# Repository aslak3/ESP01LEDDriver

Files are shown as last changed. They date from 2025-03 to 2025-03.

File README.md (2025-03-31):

# ESP01LEDDriver: a board for attaching an ESP01 to an addressable LED strip

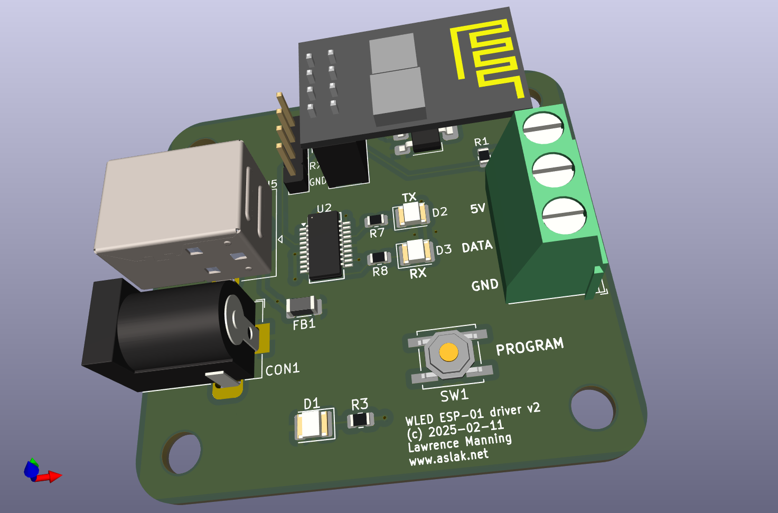
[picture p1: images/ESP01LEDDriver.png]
ESP01LEDDriver PCB


A [schematic](ESP01LEDDriver.pdf) is included here, along with the
[KiCAD](https://www.kicad.org) data files, whcih are in KiCAD 6 format.

## PCB design

The PCB is a trivial 2 layer board.

## Using

After coming across the
[ESP01](https://www.instructables.com/Getting-Started-With-the-ESP8266-ESP-01/)
I was very impressed. It seemed like an excellent solution to problems where a
very small controller board was needed, such as running
[WLED](https://kno.wled.ge) to control addressable LED strips. However the LED
strip attachment board I could find used an odd arrangement of receiving power
by attaching a USB-A plug directly to the board. I wanted to use a power lead of
some description, going to the controller board which then had the LED strip
screwed into it on terminals. As I was ordering some other boards, I thought I
would knock up this board and order it at the same time.

Power can be supplied via 5V on the barell plug, or 5V via a USB-B connector.
The [FTDI
FT231XS](https://ftdichip.com/wp-content/uploads/2021/10/DS_FT231X.pdf) is
optional: if included on the board then it is possible to program the ESP01
in-place via the USB connection. Otherwise it must either be programmed using a
dedicated board, or programmed when attached to this board but via a USB TTL (in
3.3V mode!) UART attached to the four header pins.

In either case, the PROGRAM button can be used to bring up the ESP01 in
programming mode.

## TODO

When time allows I will CAD-up a small printable case for enclosing this board.

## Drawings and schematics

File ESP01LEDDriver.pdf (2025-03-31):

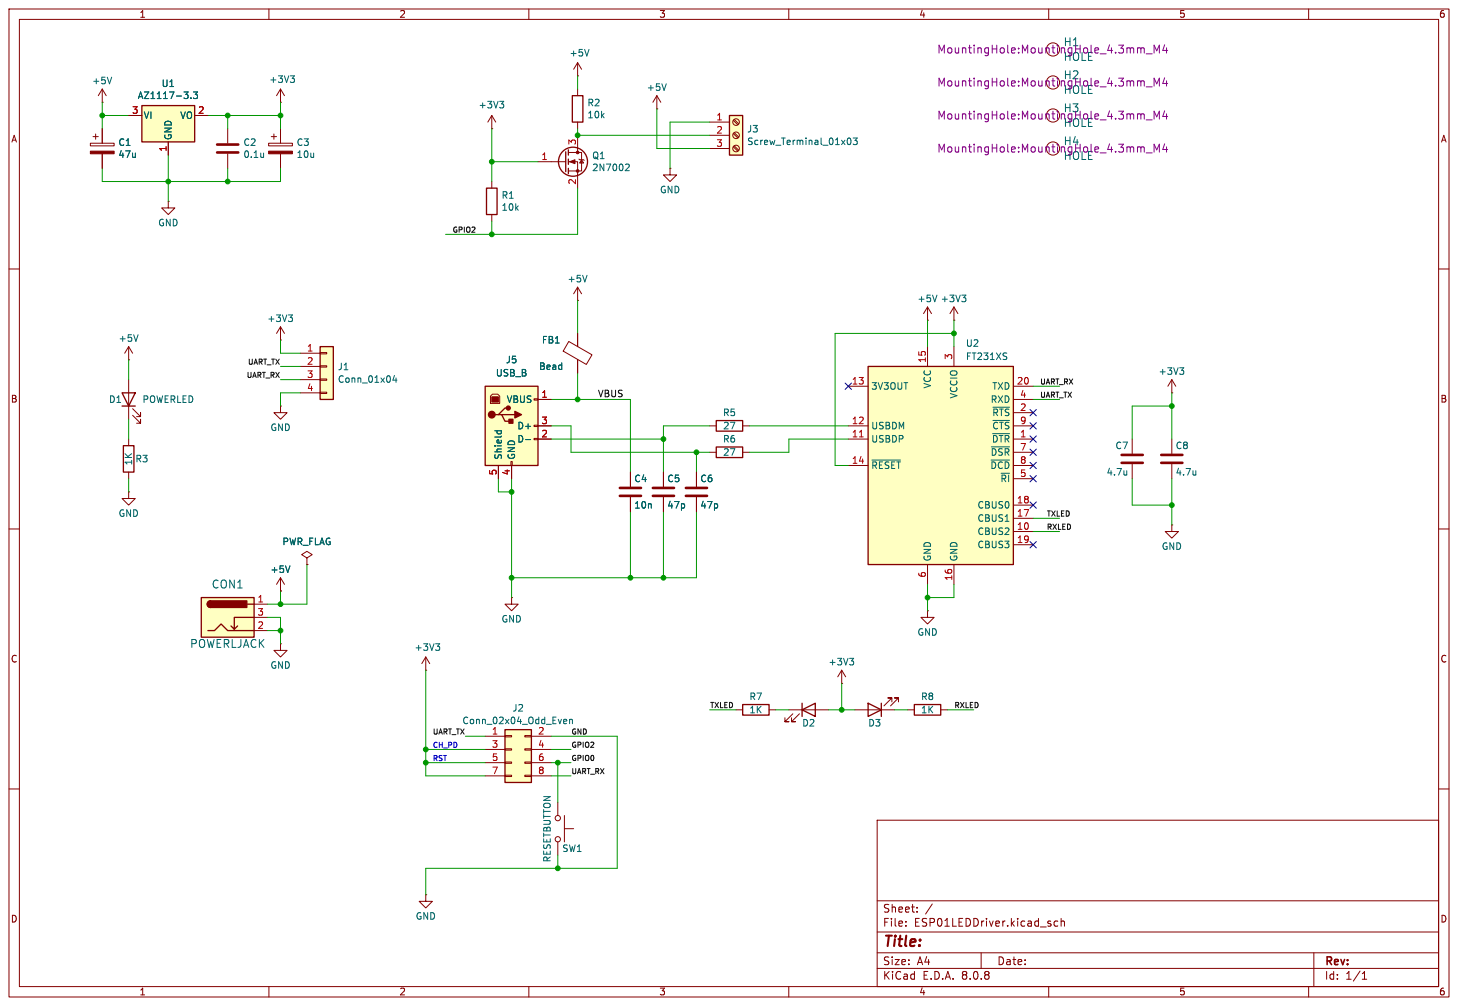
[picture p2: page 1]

Id: 1/1 Title: File: ESP01LEDDriver.kicad_sch Sheet: /

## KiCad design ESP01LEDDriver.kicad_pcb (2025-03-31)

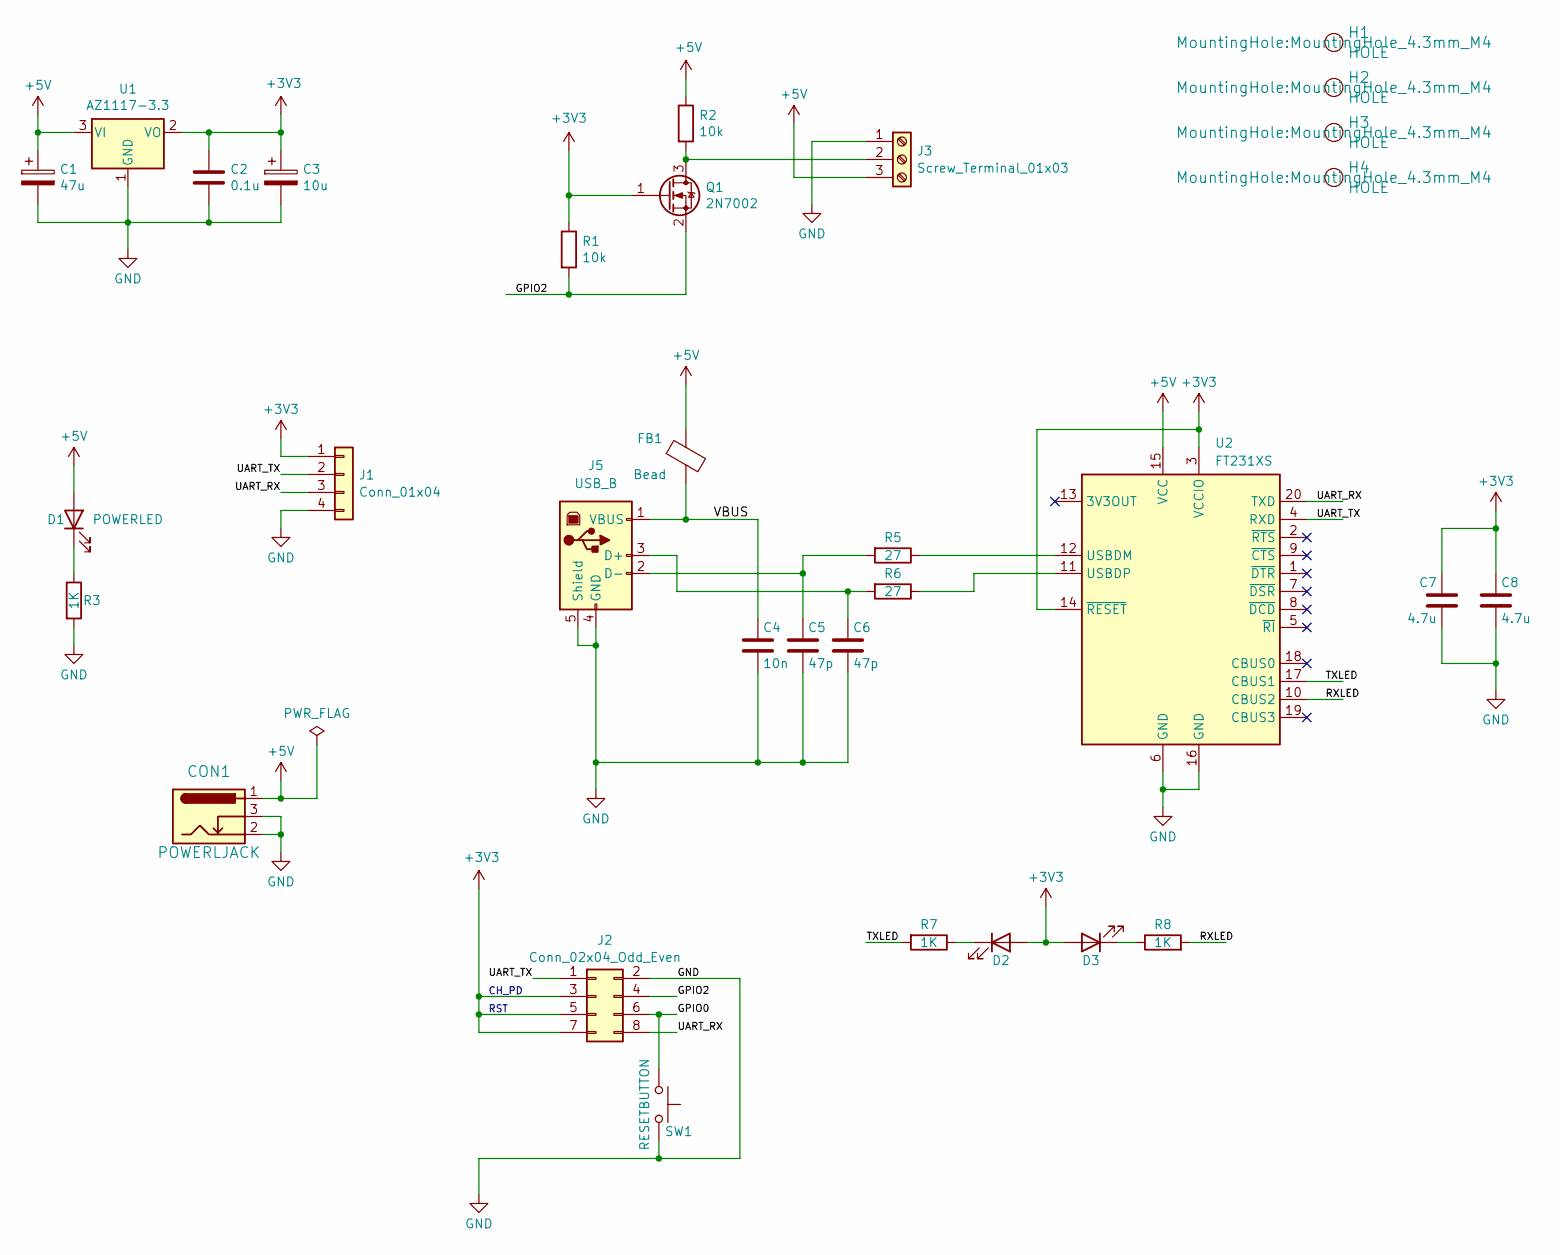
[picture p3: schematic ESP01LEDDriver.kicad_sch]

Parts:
C1: 47u; CP_EIA-7343-15_Kemet-W
C2: 0.1u; C_0805_2012Metric
C3: 10u; CP_EIA-3216-10_Kemet-I
C4: 10n; C_0805_2012Metric
C5, C6: 47p; C_0805_2012Metric
C7, C8: 4.7u; C_0805_2012Metric
CON1: POWERLJACK; BarrelJack_Horizontal
D1: POWERLED; LED_1210_3225Metric
D2, D3: UART_LED; LED_1210_3225Metric
FB1: Bead; L_1206_3216Metric
H1, H2, H3, H4: HOLE; MountingHole_4.3mm_M4
J1: Conn_01x04; PinHeader_1x04_P2.54mm_Vertical
J2: Conn_02x04_Odd_Even; PinHeader_2x04_P2.54mm_Vertical
J3: Screw_Terminal_01x03; TerminalBlock_Philmore_TB133_1x03_P5.00mm_Horizontal
J5: USB_B; USB_B_OST_USB-B1HSxx_Horizontal
Q1: 2N7002; SOT-23; LCSC C8545
R1, R2: 10k; R_0805_2012Metric; LCSC C17414
R3, R7, R8: 1K; R_0805_2012Metric
R5, R6: 27; R_0805_2012Metric
SW1: RESETBUTTON; SW_Push_1P1T_NO_CK_KSC6xxJ
U1: AZ1117-3.3; SOT-223-3_TabPin2
U2: FT231XS; SSOP-20_3.9x8.7mm_P0.635mm

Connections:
+3V3: C2.1, C3.1, C7.1, C8.1, D2.2 (A), D3.2 (A), J1.1, J2.3, J2.5, J2.7, Q1.1 (G), R1.1, U1.2 (VO), U2.3 (VCCIO), U2.14 (~RESET)
+5V: C1.1, CON1.1, D1.2 (A), FB1.1, J3.3, R2.1, U1.3 (VI), U2.15 (VCC)
/GPIO0: J2.6, SW1.1
/GPIO2: J2.4, Q1.2 (S), R1.2
/RXLED: R8.2, U2.10 (CBUS2)
/TXLED: R7.2, U2.17 (CBUS1)
/UART_RX: J1.3, J2.8, U2.20 (TXD)
/UART_TX: J1.2, J2.1, U2.4 (RXD)
/VBUS: C4.1, FB1.2, J5.1 (VBUS)
GND: C1.2, C2.2, C3.2, C4.2, C5.2, C6.2, C7.2, C8.2, CON1.2, CON1.3, J1.4, J2.2, J3.1, J5.4 (GND), J5.5 (Shield), R3.2, SW1.2, U1.1 (GND), U2.6 (GND), U2.16 (GND)
unnamed: D1.1 (K), R3.1
unnamed: D2.1 (K), R7.1
unnamed: D3.1 (K), R8.1
unnamed: J3.2, Q1.3 (D), R2.2
unnamed: C6.1, J5.3 (D+), R6.2
unnamed: C5.1, J5.2 (D-), R5.2
unnamed: R5.1, U2.12 (USBDM)
unnamed: R6.1, U2.11 (USBDP)

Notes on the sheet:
RST
CH_PD

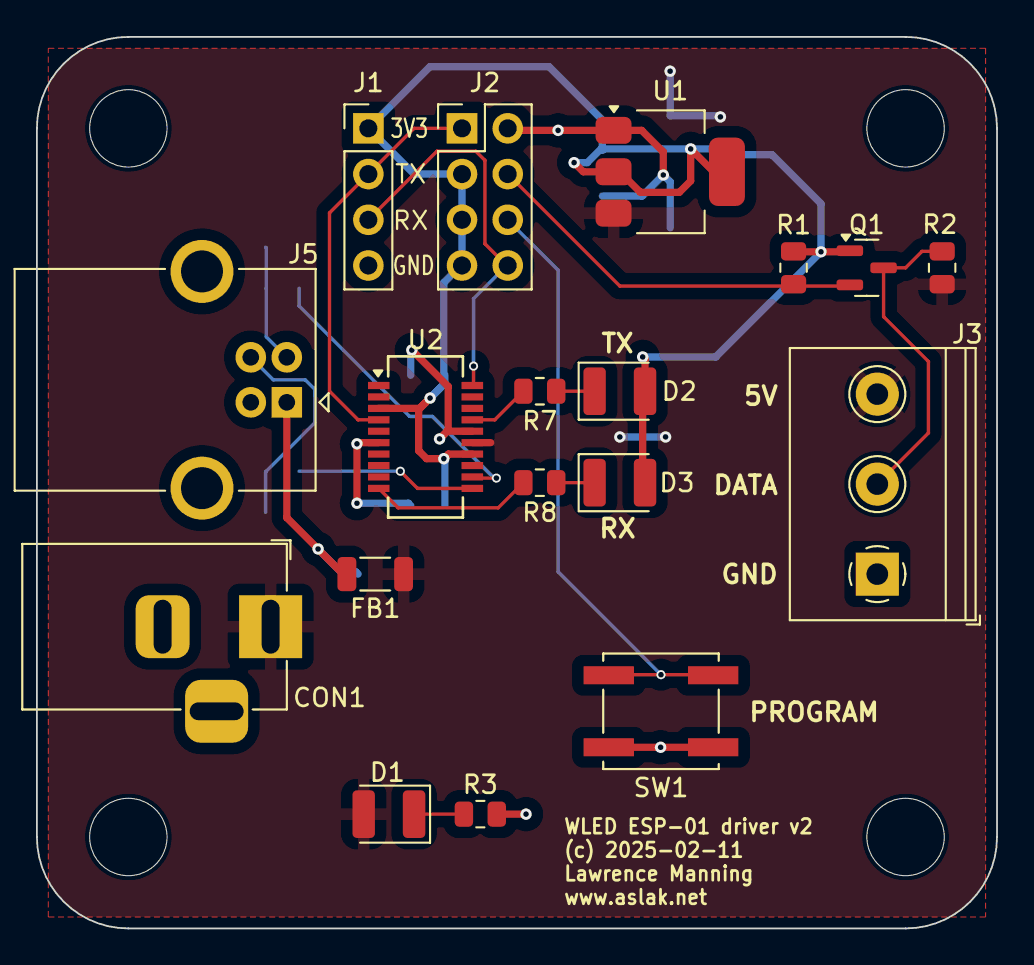
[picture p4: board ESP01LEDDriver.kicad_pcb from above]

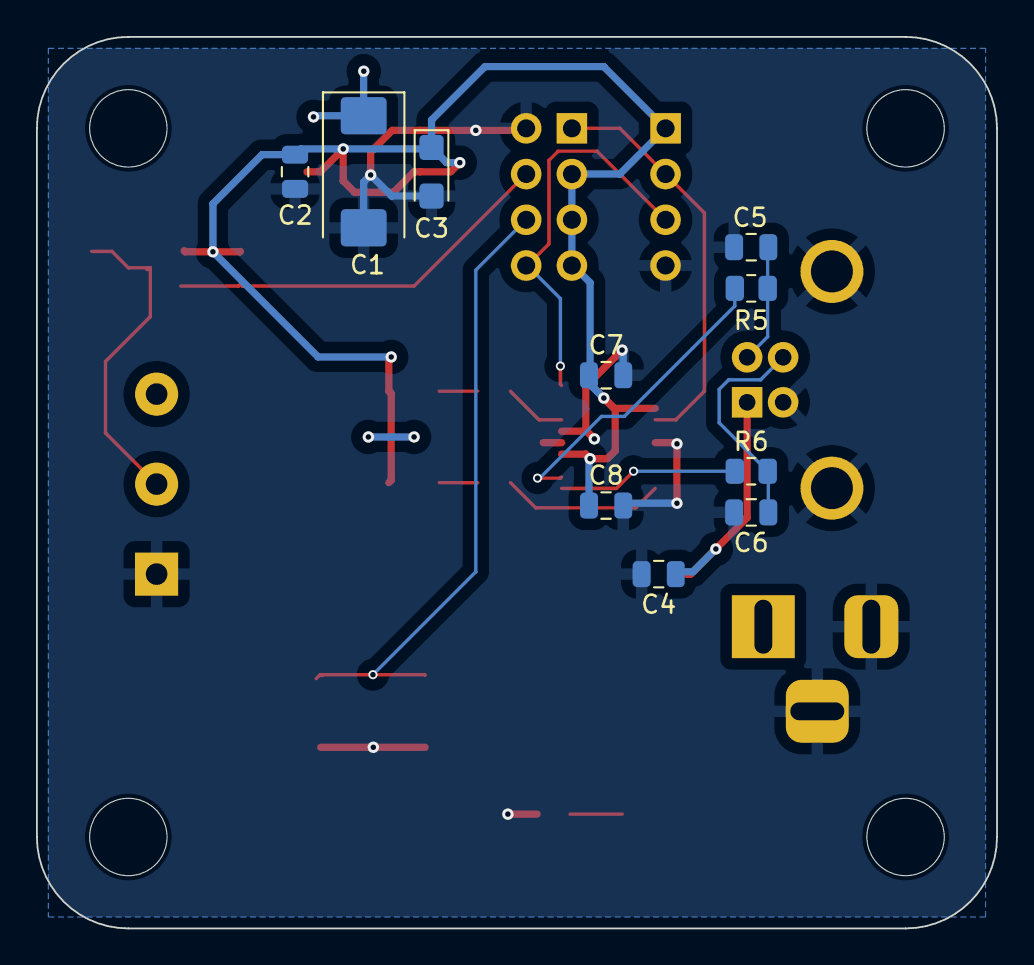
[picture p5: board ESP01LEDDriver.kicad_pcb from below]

Board: 2 copper layers, 53.3 x 49.5 mm, 32 parts (10 on the bottom side), 18 nets.

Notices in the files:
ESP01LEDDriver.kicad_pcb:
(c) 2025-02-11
